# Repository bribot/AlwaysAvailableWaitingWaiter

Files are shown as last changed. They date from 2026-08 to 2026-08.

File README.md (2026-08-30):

# AlwaysAvailableWaitingWaiter

Built as an entry for a Seeed Studio contest, this is a little table-side gadget that lets restaurant guests order **by voice**, tracks what's coming and when, and shows it all on an e-paper display. Tap it onto a table with an NFC tag, press the button, say what you want, and it takes it from there.

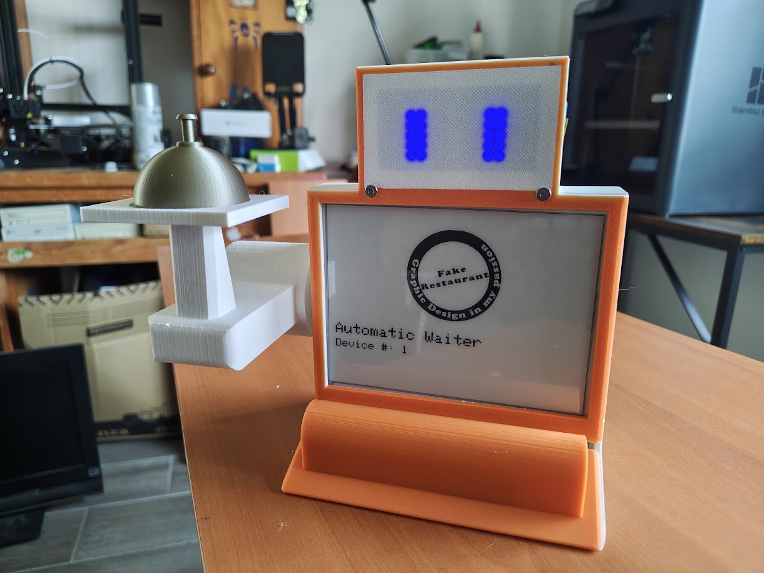
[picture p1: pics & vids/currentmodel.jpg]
Current build: orange 3D-printed waiter with LED eyes and e-paper order screen
<br>
<sub>The current model — eyes, e-paper screen, and a very serious "Fake Restaurant" test menu.</sub>

## What it actually does

- **Listens.** Press the button, say your order out loud, let go. No app, no menu-fumbling.
- **Takes orders.** You can add thing to your order just by voice.
- **Knows where it lives.** Tap an NFC tag at a table and the puck reassigns itself — same hardware, any table.
- **Has feelings, sort of.** A pair of LED matrix "eyes" blink, look around, and react while it's listening or thinking.
- **Puts it on the board.** A table-side e-paper display shows the live order — items, prices, prep time — updating as dishes go out.

<p align="center">
  <video src="pics%20&%20vids/screen_video.mp4" controls width="480">
    Your viewer doesn't do inline video — <a href="pics%20&%20vids/screen_video.mp4">watch the e-paper display in action here</a>.
  </video>
</p>

## The hardware

Two custom devices, built around these core parts:

- **5.83" Monochrome eInk / ePaper Display** — 648×480 pixels, the table-side order board
- **XIAO ePaper Display Board (ESP32-S3) — EE04** — drives the display
- **reSpeaker Lite 2-Mic Array Voice Kit** — the Waiter's ears and voice

| Device | What it's for | Lives in |
|---|---|---|
| **The Waiter** | mic + speaker, NFC reader, LED "eyes", call button | [`Audio/seeedSpeaker`](Audio/seeedSpeaker) |
| **The Board** | e-paper table display showing the live order | [`Screen`](Screen) |

Under the hood there's also an NFC reader board (PN532) for the table-tap trick:

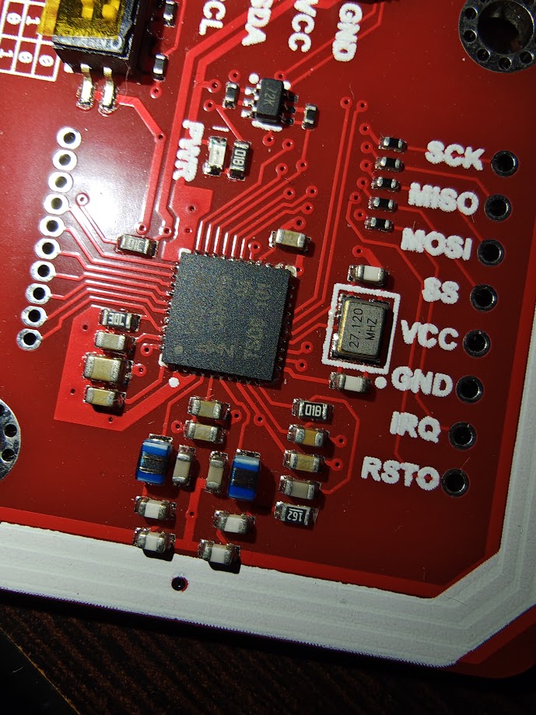
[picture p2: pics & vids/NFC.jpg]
Close-up of the PN532 NFC reader board
<br>
<sub>The part that lets the Waiter figure out which table it's sitting on.</sub>

Everything physical was designed from scratch and printed at home:

- **[`ME/`](ME)** — the enclosure: body, bell-shaped dome, arm, bottom plate (with a battery variant), all as SolidWorks parts + STL + gcode pre-sliced.
- **[`EE/button`](EE/button)** — a small custom KiCad PCB for the call button, gerbers included.

## How it works

The devices don't do the thinking themselves — they talk over Wi-Fi to a small backend that keeps track of tables, menus, and orders, and turns a voice clip into a structured order using speech recognition plus a language model on the other end (OLLAMA+whisper).

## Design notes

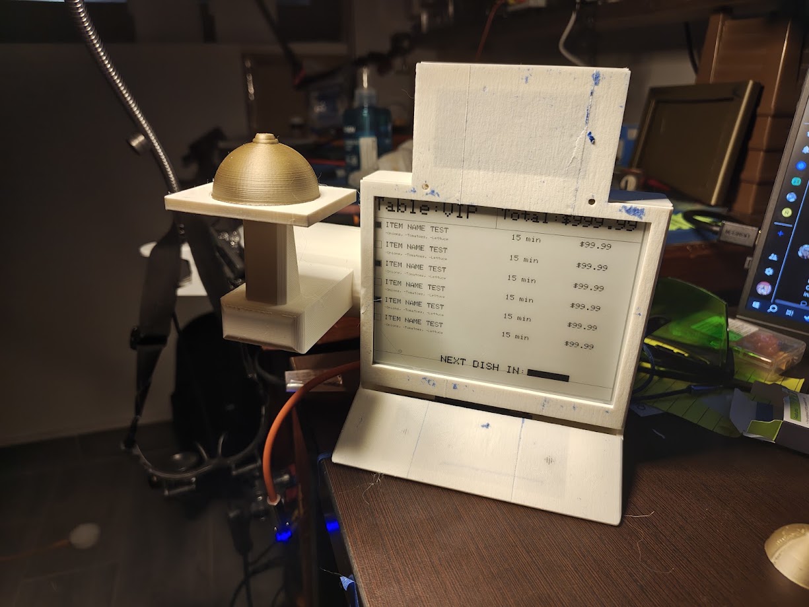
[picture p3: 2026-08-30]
pics & vids/earlyversion.jpg

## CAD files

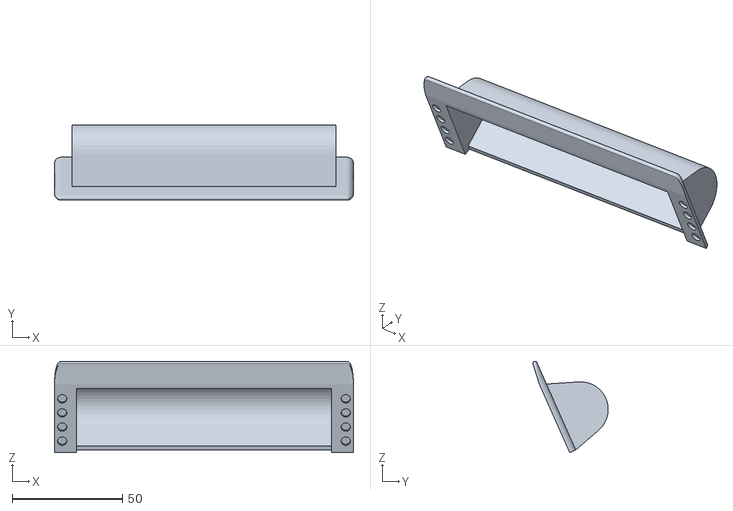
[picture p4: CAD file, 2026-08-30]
ME/bottom_plate_battery.STL
135.6 x 34.2 x 41.4

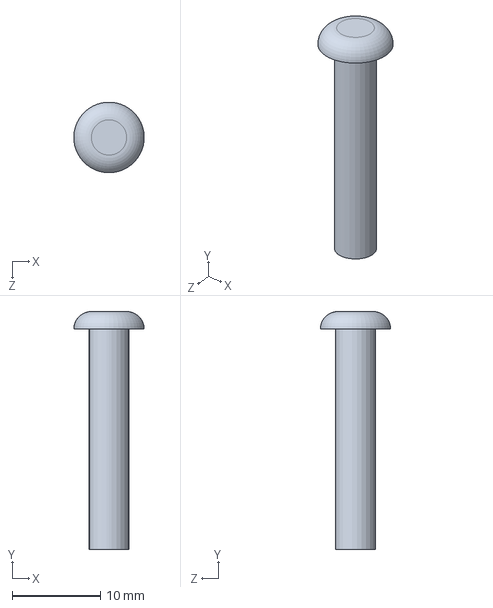
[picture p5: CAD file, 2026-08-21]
ME/bell_top.SLDPRT
8.00 x 27.0 x 7.99 mm

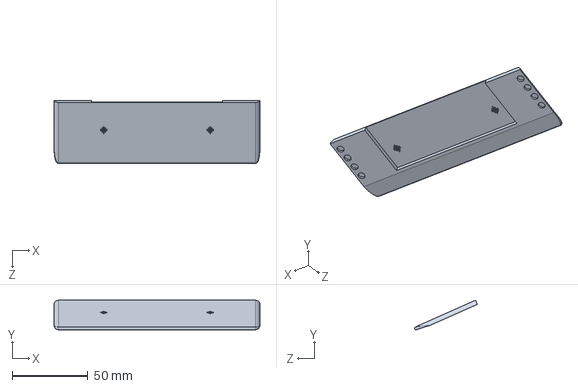
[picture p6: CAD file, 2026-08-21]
ME/bottom_plate.SLDPRT
135.6 x 19.5 x 41.4 mm

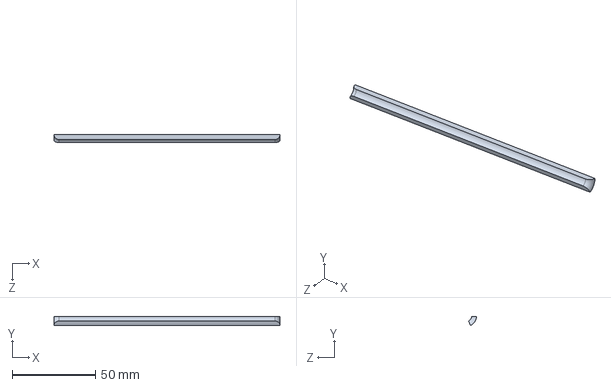
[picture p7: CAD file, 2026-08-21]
ME/middle_union.SLDPRT
135.6 x 5.48 x 4.78 mm

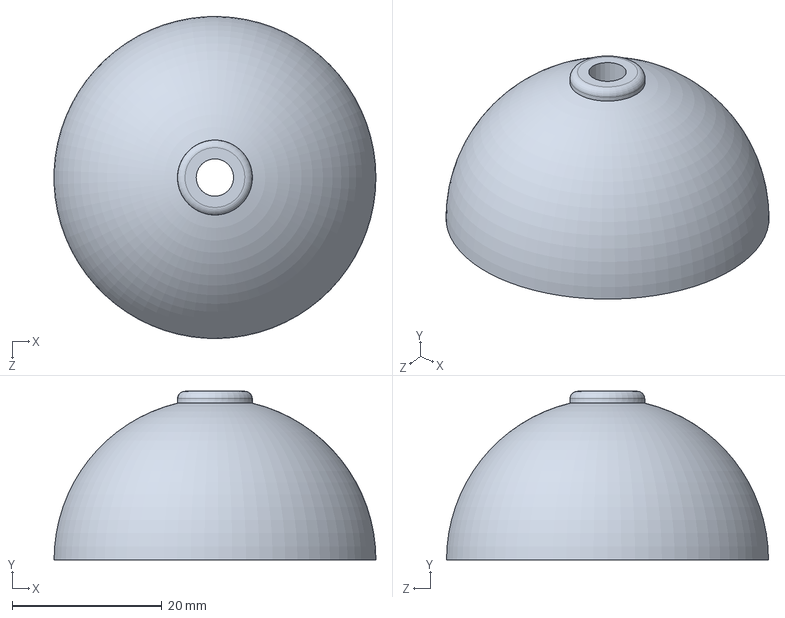
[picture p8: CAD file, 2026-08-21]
ME/bell.SLDPRT
43.0 x 22.5 x 43.0 mm

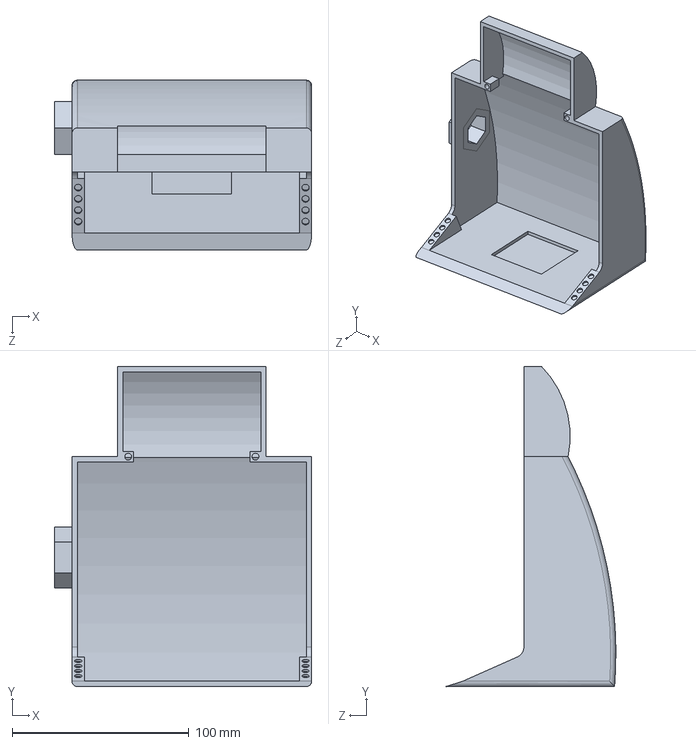
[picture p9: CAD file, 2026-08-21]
ME/body.SLDPRT
145.6 x 181.0 x 96.0 mm

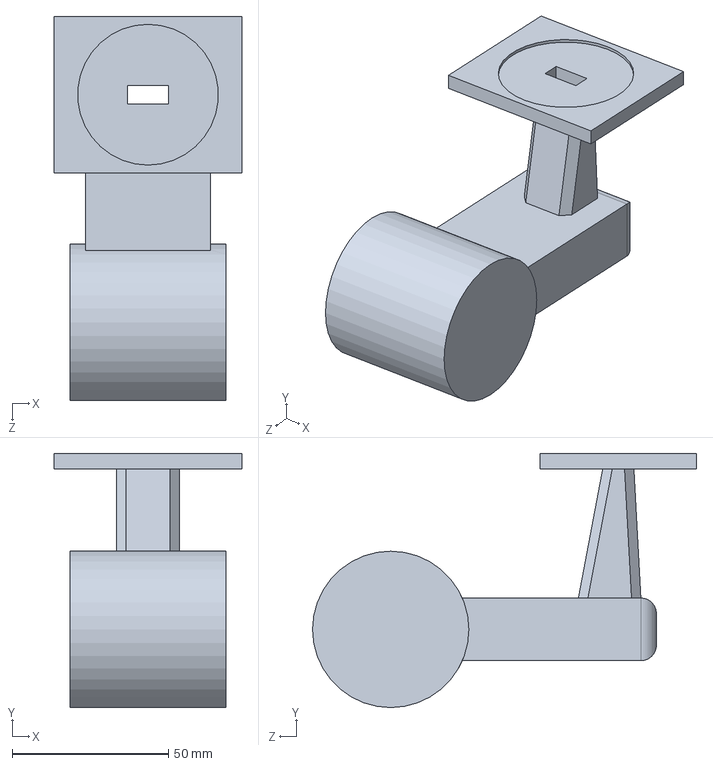
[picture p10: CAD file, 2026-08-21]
ME/arm.SLDPRT
60.0 x 81.3 x 122.8 mm

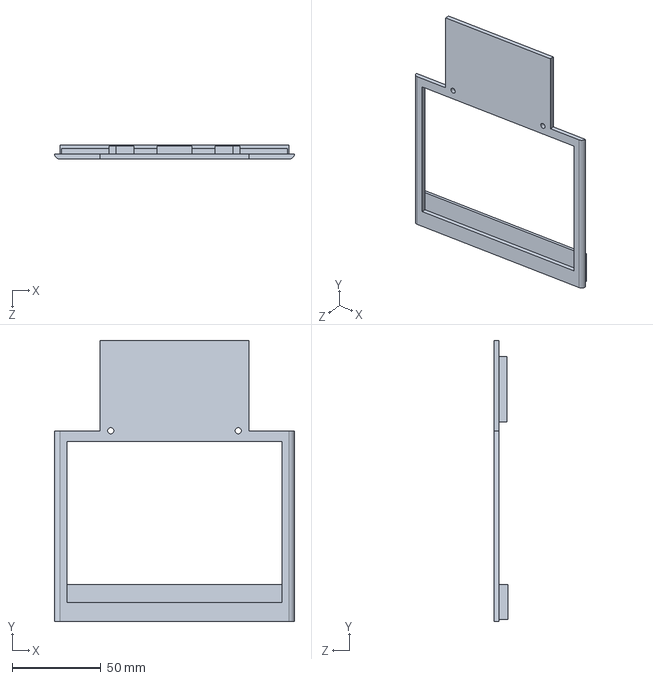
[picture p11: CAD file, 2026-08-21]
ME/front_plate.SLDPRT
135.6 x 158.8 x 8.00 mm

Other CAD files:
ME/arm.STL
ME/bell.STL
ME/bell_top.STL
ME/body.STL
ME/bottom_plate.STL
ME/front_plate.STL
ME/middle_union.STL

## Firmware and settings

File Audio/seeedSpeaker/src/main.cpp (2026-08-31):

/*
 * Voice ordering mic - XIAO ESP32S3 + ReSpeaker Lite
 *
 * Push-to-talk: hold the button on D3, speak, release. The clip goes to the
 * restaurant server over a WebSocket, which hands it to Gemini and stages the
 * parsed items into that table's pending order for confirmation.
 *
 * The table number isn't hardcoded - on boot (and on every reconnect) this
 * calls GET /device/{DEVICE_NUMBER}, the same lookup the e-paper display
 * uses, so reassigning a table's hardware doesn't require reflashing.
 *
 * Wire protocol (see Server/README.md, "Voice ordering"):
 *   -> {"type":"start"}     button pressed
 *   -> <binary frames>      raw 16-bit mono PCM @ 16 kHz, little-endian
 *   -> {"type":"stop"}      button released
 *   <- ready | listening | processing | result | error | cancelled | pong
 *
 * The ReSpeaker Lite is the I2S master and gives us 32-bit stereo frames. We
 * take the left channel and shift down to 16-bit before sending: a quarter of
 * the bytes over Wi-Fi, and exactly what the server expects.
 */
#include <Arduino.h>

#include <ArduinoJson.h>
#include <ArduinoWebsockets.h>
#include <HTTPClient.h>
#include <WiFi.h>
#include <Wire.h>
#include <Adafruit_PN532.h>
#include <Adafruit_GFX.h>
#include <Adafruit_LEDBackpack.h>

#include "AudioTools.h"
#include "board_pins.h"
#include "secrets.h"
#include "eye_emotes.h"
#include <Adafruit_NeoPixel.h>

using namespace websockets;

// ------------------------------- config -------------------------------------


#define LED_MATRIX_LEFT 0x70
#define LED_MATRIX_RIGHT 0x71

static const char *WIFI_SSID_ = WIFI_SSID;
static const char *WIFI_PASS_ = WIFI_PASSWORD;
String serverURL = SERVER_URL;
static const uint16_t PORT = PORT_NUM;
static uint8_t deviceNumber = DEVICE_NUMBER;

// Resolved from GET /device/{DEVICE_NUMBER}".
static int TABLE_NUMBER = 0;

static const int BUTTON_PIN = D3;      // push-to-talk, active LOW
static const uint32_t SAMPLE_RATE = 16000;
static const uint16_t DEBOUNCE_MS = 40;
static const uint32_t MAX_UTTERANCE_MS = 30000;  // server truncates past this
static const uint32_t RECONNECT_MS = 3000;

// I2S frames arrive 32-bit stereo; we send 16-bit mono.
static const size_t FRAMES_PER_CHUNK = 256;
static const size_t I2S_CHUNK_BYTES = FRAMES_PER_CHUNK * 2 * sizeof(int32_t);

// ------------------------------- globals ------------------------------------
static Adafruit_NeoPixel pixels(NUMPIXELS, PIN, NEO_GRB + NEO_KHZ800);
static bool pixelsStarted = false;

I2SStream i2sIn;
AudioInfo micInfo(SAMPLE_RATE, 2, 32);
WebsocketsClient ws;

static int32_t i2sBuffer[FRAMES_PER_CHUNK * 2];
static int16_t pcmBuffer[FRAMES_PER_CHUNK];

static bool wsConnected = false;
static bool capturing = false;
static bool lastButtonDown = false;
static uint32_t lastButtonChange = 0;
static uint32_t captureStartedAt = 0;
static uint32_t lastReconnectAttempt = 0;
static uint16_t nfcMisses = 0;
static const uint16_t NFC_MISS_RESET_THRESHOLD = 10;


volatile bool buttonIsrPending = false;
volatile bool buttonIsrState = false;
volatile uint32_t buttonIsrTime = 0;


static uint32_t pressIsrTime = 0;
static uint32_t pumpCallCount = 0;
static uint32_t pumpBytesSent = 0;

Adafruit_PN532 nfc(-1, -1, &Wire);
Adafruit_8x8matrix eyeLeft = Adafruit_8x8matrix();
Adafruit_8x8matrix eyeRight = Adafruit_8x8matrix();

uint8_t uid[7];
uint8_t uidLength;

const uint8_t table1_uid[] = {0x04,0xAF, 0xD3, 0xAA, 0x8B, 0x26 ,0x81};
const uint8_t table2_uid[] = {0x04, 0x33, 0xCA, 0xAA, 0x8B, 0x26, 0x81};
const uint8_t table3_uid[] = {0x04, 0x42, 0x11, 0xAB, 0x8B, 0x26, 0x81};

// ------------------------------ prototypes ----------------------------------
void connectWiFi();
bool fetchAssignedTable(int &tableNumberOut);
bool connectSocket();
void onWsMessage(WebsocketsMessage message);
void onWsEvent(WebsocketsEvent event, String data);
void startCapture();
void stopCapture();
void cancelCapture();
void pumpAudio();
void setStatus(uint8_t r, uint8_t g, uint8_t b);
void initNFC();
void initMatrix(Adafruit_8x8matrix &m, uint8_t addr);
void showEyeEmote(Adafruit_8x8matrix &m, const uint8_t *emote);
void nfcTagRecon();
void changeTableNumber(uint8_t newTableNumber);

// void scanI2CBus() {
//   Serial.println("Scanning I2C bus...");
//   uint8_t found = 0;
//   for (uint8_t addr = 1; addr < 127; addr++) {
//     Wire.beginTransmission(addr);
//     if (Wire.endTransmission() == 0) {
//       Serial.printf("  device found at 0x%02X\n", addr);
//       found++;
//     }
//   }
//   if (found == 0) {
//     Serial.println("  no I2C devices found - check wiring/power");
//   }
// }

void showEyeEmote(Adafruit_8x8matrix &m, const uint8_t *emote){
    m.clear();
    m.drawBitmap(0,0,emote,8,8,LED_ON);
    m.writeDisplay();
}

void setEyes(const uint8_t *emote){
    showEyeEmote(eyeLeft,emote);
    showEyeEmote(eyeRight,emote);
}


void blinkAnimation(){
    setEyes(idle_eye);
    delay(100);
    setEyes(closed_eye);
    delay(100);
    setEyes(idle_eye);
}

void happyAnimation(){
    for(int i=0; i<3;i++){
    setEyes(happy1);
    delay(100);
    setEyes(happy2);
    delay(100);
}
}

void sideEyeAnimation(){
    setEyes(leftidle_eye);
    delay(100);
    setEyes(rightidle_eye);
    delay(100);
    setEyes(idle_eye);
}

void changeTableAnimation(uint8_t table){
    switch (table)
    {
    case 1:
        setEyes(tag1);
        break;
    case 2:
        setEyes(tag2);
        break;
    case 3:
        setEyes(tag3);
        break;
    
    default:
        break;
    }
    delay(1000);
    happyAnimation();
    sideEyeAnimation();
}


// -------------------------------- setup -------------------------------------
void setup() {
    Serial.begin(115200);
    pinMode(BUTTON_PIN, INPUT_PULLUP);
    Wire.begin();

    // delay(3000); // delay so i can connect to the serial, remove!
    //scanI2CBus();
    initNFC();
    initMatrix(eyeLeft, LED_MATRIX_LEFT);
    initMatrix(eyeRight, LED_MATRIX_RIGHT);
    happyAnimation();
    blinkAnimation();

    setStatus(40, 0, 0);  // red until we're online
    connectWiFi();

    while (!fetchAssignedTable(TABLE_NUMBER)) {
        Serial.println("[device] lookup failed, retrying...");
        delay(2000);
    }
    Serial.printf("[device] mic %d assigned to table %d\n", DEVICE_NUMBER, TABLE_NUMBER);

    auto cfg = i2sIn.defaultConfig(RX_MODE);
    cfg.copyFrom(micInfo);
    cfg.i2s_format = I2S_STD_FORMAT;
    cfg.is_master = false;
    cfg.use_apll = false;
    cfg.pin_bck = 8;
    cfg.pin_ws = 7;
    cfg.pin_data = 43;
    cfg.pin_data_rx = 44;
    i2sIn.begin(cfg);

    ws.onMessage(onWsMessage);
    ws.onEvent(onWsEvent);
    connectSocket();
}

// -------------------------------- loop --------------------------------------
void loop() {
    if (WiFi.status() != WL_CONNECTED) {
        wsConnected = false;
        capturing = false;
        setStatus(40, 0, 0);
        connectWiFi();
        return;
    }

    if (!wsConnected) {
        capturing = false;
        if (millis() - lastReconnectAttempt > RECONNECT_MS) {
            lastReconnectAttempt = millis();
            connectSocket();
        }
        delay(10);
        return;
    }

    ws.poll();

    // ---- debounced push-to-talk ----
    bool buttonDown = digitalRead(BUTTON_PIN) == LOW;
    //Serial.printf("[mic] button %s\n", buttonDown ? "down" : "up");
    if (buttonDown != lastButtonDown && millis() - lastButtonChange > DEBOUNCE_MS) {
        lastButtonChange = millis();
        lastButtonDown = buttonDown;
        if (buttonDown) {
            setEyes(attention_eye);
            startCapture();
        } else {
            stopCapture();
        }
    }

    if (capturing) {
        //Serial.printf("Capturing...");
        pumpAudio();
        // Don't let a stuck button stream forever.
        if (millis() - captureStartedAt > MAX_UTTERANCE_MS) {
            Serial.println("[mic] max utterance reached");
            stopCapture();
        }
    } else {
        // Keep draining I2S so the DMA buffers don't overflow with stale audio.
        i2sIn.readBytes((uint8_t *)i2sBuffer, I2S_CHUNK_BYTES);

        bool tagPresent = nfc.readPassiveTargetID(PN532_MIFARE_ISO14443A, uid, &uidLength, 100);

        if (tagPresent){
            nfcMisses = 0;
            nfcTagRecon();
        } else if (++nfcMisses > NFC_MISS_RESET_THRESHOLD) {
            // weird bug
            // https://github.com/espressif/arduino-esp32/issues/11374
            nfcMisses = 0;
            
        }
        Wire.end();
        Wire.begin();
    }
}

void initNFC(){
    nfc.begin();
    uint32_t version = nfc.getFirmwareVersion();
    if (!version) {
        Serial.println("PN532 not found!!");
        while (true) {
            delay(1000);
        }
    }
    nfc.SAMConfig();
}

void initMatrix(Adafruit_8x8matrix &m, uint8_t addr){
    if (!m.begin(addr, &Wire)){
        Serial.printf("Matrix %02X not found",addr);
        return;
    } 
    m.setBrightness(8);
    m.clear();
    m.writeDisplay();
}


void nfcTagRecon(){
    // Serial.print("Tag UID:");
    // for (uint8_t i = 0; i < uidLength; i++) {
    //   Serial.printf(" %02X", uid[i]);
    // }
    // Serial.println();
    // if (uidLength == sizeof(table1_uid) && memcmp(uid, table1_uid, uidLength) == 0){
    //   showEyeEmote(eyeLeft, tag_found_bmp);
    //   showEyeEmote(eyeRight, tag_found_bmp);
    // }
    uint8_t newtable = 0;
    if (uidLength == sizeof(table1_uid)){
        
            if (uid[1] == table1_uid[1]){
                newtable = 1;
            } else if (uid[1] == table2_uid[1]){
                newtable = 2;
            } else if (uid[1] == table3_uid[1])
            {
                newtable = 3;
            }
            if(newtable != 0 && newtable != TABLE_NUMBER){
                changeTableNumber(newtable);
                changeTableAnimation(newtable);
        }
        
    }
}

void changeTableNumber(uint8_t newTableNumber) {
    Serial.printf("Table changed to %d",newTableNumber);
    HTTPClient http;
    String url = serverURL + ":" + String(PORT) + "/device/" + String(deviceNumber);
    http.begin(url);
    http.addHeader("Content-Type", "application/json");
    http.PUT("{\"table_number\":" + String(newTableNumber) + "}");
    http.end();
    TABLE_NUMBER = newTableNumber;
    connectSocket();
}

// ------------------------------ networking ----------------------------------
void connectWiFi() {
    if (WiFi.status() == WL_CONNECTED) return;

    Serial.printf("[wifi] connecting to %s", WIFI_SSID_);
    WiFi.mode(WIFI_STA);
    WiFi.begin(WIFI_SSID_, WIFI_PASS_);
    while (WiFi.status() != WL_CONNECTED) {
        delay(500);
        Serial.print(".");
    }
    Serial.printf("\n[wifi] connected, ip=%s\n", WiFi.localIP().toString().c_str());
}

bool fetchAssignedTable(int &tableNumberOut) {
    HTTPClient http;
    String url = serverURL + ":" + String(PORT) + "/device/" + String(DEVICE_NUMBER);
    http.begin(url);
    int httpCode = http.GET();

    bool ok = false;
    if (httpCode == HTTP_CODE_OK) {
        String response = http.getString();
        JsonDocument doc;
        if (!deserializeJson(doc, response)) {
            tableNumberOut = doc["table_number"].as<int>();
            ok = true;
        } else {
            Serial.println("[device] failed to parse JSON");
        }
    } else {
        Serial.printf("[device] GET failed, error: %s\n", http.errorToString(httpCode).c_str());
    }
    http.end();
    return ok;
}

bool connectSocket() {
    ws.close();
    int fetched;
    if (fetchAssignedTable(fetched)) {
        if (fetched != TABLE_NUMBER) {
            Serial.printf("[device] table changed %d -> %d\n", TABLE_NUMBER, fetched);
        }
        TABLE_NUMBER = fetched;
    } else {
        Serial.println("[device] lookup failed, using last known table");
    }
    String host = serverURL;
    host.replace("http://", "");

    char url[160];
#ifdef API_KEY_STR
    snprintf(url, sizeof(url), "ws://%s:%u/table/%d/voice?device=%s&api_key=%s", host.c_str(),
             PORT, TABLE_NUMBER, DEVICE_NAME, API_KEY_STR);
#else
    snprintf(url, sizeof(url), "ws://%s:%u/table/%d/voice?device=%u", host.c_str(), PORT,
             TABLE_NUMBER, deviceNumber);
#endif

    Serial.printf("[ws] connecting to %s\n", url);
    wsConnected = ws.connect(url);
    if (wsConnected) {
        Serial.println("[ws] connected");
        setStatus(0, 30, 0);  // green: idle and ready
    } else {
        Serial.println("[ws] connect failed");
        setStatus(40, 0, 0);
    }
    return wsConnected;
}

void onWsEvent(WebsocketsEvent event, String data) {
    if (event == WebsocketsEvent::ConnectionClosed) {
        Serial.println("[ws] closed");
        wsConnected = false;
        capturing = false;
        setStatus(40, 0, 0);
    }
}

void onWsMessage(WebsocketsMessage message) {
    JsonDocument doc;
    if (deserializeJson(doc, message.data())) {
        Serial.println("[ws] unparseable message");
        return;
    }

    const char *type = doc["type"] | "";

    if (!strcmp(type, "ready")) {
        Serial.printf("[ws] ready, table=%d voice_enabled=%d\n", (int)(doc["table"] | 0),
                      (int)(doc["enabled"] | false));
        if (!(doc["enabled"] | false)) {
            Serial.println("[ws] server has no GEMINI_API_KEY - orders will fail");
            setStatus(40, 20, 0);  // amber: connected but voice is disabled
        }

    } else if (!strcmp(type, "listening")) {
        setStatus(0, 0, 60);  // blue: recording

    } else if (!strcmp(type, "processing")) {
        setStatus(30, 20, 0);  // amber: waiting on Gemini
        setEyes(wait_eye);
        Serial.printf("[ws] processing %.2fs of audio\n", (float)(doc["seconds"] | 0.0));

    } else if (!strcmp(type, "result")) {
        Serial.printf("[ws] heard: %s\n", doc["transcript"] | "");
        if (doc["confirmed"] | false) {
            Serial.println("      confirmed - pending order sent to the kitchen");
        } else if (doc["cancelled"] | false) {
            Serial.println("      cancelled - pending order cleared");
        } else {
            for (JsonObject item : doc["items"].as<JsonArray>()) {
                Serial.printf("      %dx %s%s\n", (int)(item["quantity"] | 1),
                              item["name"] | "?",
                              (item["matched"] | false) ? "" : "  <-- NOT ON MENU");
            }
            Serial.printf("[ws] %d matched, %d unmatched, staged to pending\n",
                          (int)(doc["matched_count"] | 0), (int)(doc["unmatched_count"] | 0));
        }
        setStatus(0, 30, 0);
        happyAnimation();
        setEyes(idle_eye);

    } else if (!strcmp(type, "error")) {
        Serial.printf("[ws] error: %s\n", doc["message"] | "");
        setStatus(60, 0, 0);
        delay(400);
        setStatus(0, 30, 0);
        setEyes(error);
        delay(1000);
        sideEyeAnimation();

    } else if (!strcmp(type, "cancelled")) {
        setStatus(0, 30, 0);
        setEyes(sad_eye);
        delay(1000);
        sideEyeAnimation();
    }
}

// -------------------------------- capture -----------------------------------

void startCapture() {
    if (!wsConnected) return;
    Serial.println("[mic] start");

    // Drop whatever the DMA buffered while we were idle, so the clip starts at
    // the button press instead of a second earlier.
    for (int i = 0; i < 4; i++) {
        i2sIn.readBytes((uint8_t *)i2sBuffer, I2S_CHUNK_BYTES);
    }

    capturing = true;
    captureStartedAt = millis();
    pumpCallCount = 0;
    pumpBytesSent = 0;
    ws.send("{\"type\":\"start\"}");
}

void stopCapture() {
    if (!capturing) return;
    capturing = false;
    Serial.println("[mic] stop");
    ws.send("{\"type\":\"stop\"}");
    setEyes(wait_eye);
}

void cancelCapture() {
    if (!capturing) return;
    capturing = false;
    ws.send("{\"type\":\"cancel\"}");
}

void pumpAudio() {
    pumpCallCount++;
    size_t bytesRead = i2sIn.readBytes((uint8_t *)i2sBuffer, I2S_CHUNK_BYTES);
    if (bytesRead < sizeof(int32_t) * 2) return;

    // 32-bit stereo -> 16-bit mono. Left channel only: on the ReSpeaker Lite the
    // processed mic signal is there, and averaging both channels just halves it.
    size_t frames = bytesRead / (sizeof(int32_t) * 2);
    for (size_t i = 0; i < frames; i++) {
        pcmBuffer[i] = (int16_t)(i2sBuffer[i * 2] >> 16);
    }

    if (!ws.sendBinary((const char *)pcmBuffer, frames * sizeof(int16_t))) {
        Serial.println("[ws] send failed, dropping utterance");
        capturing = false;
        wsConnected = false;
        return;
    }
    pumpBytesSent += frames * sizeof(int16_t);
}

// -------------------------------- status LED --------------------------------

void setStatus(uint8_t r, uint8_t g, uint8_t b) {
    if (!pixelsStarted) {
        pixels.begin();
        pixelsStarted = true;
    }
    pixels.setPixelColor(0, pixels.Color(r, g, b));
    pixels.show();
}

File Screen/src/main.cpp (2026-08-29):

#include <Arduino.h>
#include "TFT_eSPI.h"
#include "layout.h"
#include "secrets.h"
#include "ArduinoJson.h"
#include "HTTPClient.h"
#include "restaurant.h"

#ifdef EPAPER_ENABLE // Only compile this code if the EPAPER_ENABLE is defined in User_Setup.h
EPaper epaper;
#endif

JsonDocument doc;

// ------------Config ------------
#define deviceNumber 1

#define SleepMode 0
#define NormalMode 1
#define WaiterMode 2

#define NormalModeDelay 3000
#define WaiterModeDelay 1000
#define SleepModeDelay 10000


const char* ssid     = WIFI_SSID;
const char* password = WIFI_PASSWORD;

String serverURL = SERVER_URL;
char maxRows = 8;
// -------------------------------
// -----------globals -----------

uint8_t row = 0;
uint8_t defaultFontSize = 3;
uint8_t timePassed = 9;
char mode = NormalMode;
String jsonResponse;
String lasjsonResponse;


static char* TableString = "Table:";
//uint8_t TableNumber = 4;
static char* TotalString = "Total:";
String TotalAmount = "$0.00";
// char* TimeString = "NEXT DISH IN:";

RTC_DATA_ATTR bool mainDrawn = false;
RTC_DATA_ATTR uint8_t TableNumber = 0;
RTC_DATA_ATTR uint8_t OrderID = 0;
RTC_DATA_ATTR bool splashDrawn = false;
bool itemsDrawn = false; 

void drawPartialString(const char* text, Rect_t rect, uint8_t fontsize = defaultFontSize);
void drawItem(int row, const char* name, const char* price, const char* detail, const float time, bool checked = false);
void drawCheckBox(Rect_t rect, bool checked);
void startupScreen();
void drawTotal(const char* totalAmount);
void drawProgressBar(float progress);
bool fetchOrders(String &jsonResponse, uint8_t tableNumber);
void normalMode();
void waiterMode();
void sleepMode();
void fetchCurrentTable();
void changeTableNumber(uint8_t newTableNumber);
void drawWaiterModeScreen();
bool fetchPendingOrders(String &jsonResponse, uint8_t tableNumber);
bool checkPending();
void goToSleep(uint32_t ms);
void drawSplashScreen();



// char* ItemName = "ITEM NAME TEST";
// char* ItemPrice = "$99.99";
// char* ItemDetail = "-Onions, -Tomatoes, -Lettuce";
// char* ItemTime = "15 min";
// bool ItemDelivered = false;

float NexDishProgress = 0.5;

void setup()
{
    //delay(3000);
    Serial.begin(115200);
    Serial.println("Starting up...");

    // Connect to Wi-Fi
    WiFi.begin(ssid, password);
    Serial.print("Connecting to Wi-Fi");
    while (WiFi.status() != WL_CONNECTED) {
        delay(500);
        Serial.print(".");
    }
    Serial.println();
    Serial.println("Connected to Wi-Fi");
    Serial.print("IP Address: ");
    Serial.println(WiFi.localIP());

    fetchCurrentTable();
    //Serial.printf("Current table number: %s\n", TableNumber.c_str());
    epaper.begin();
    epaper.fillScreen(TFT_WHITE);
    // Rect_t testRect = getItemRect(0);
    //Rect_t testRect_t = getItemTimeRect(testRect);
    
    

    if (OrderID == 0) {
        Serial.println("No order ID found, going to sleep");
        sleepMode();
    }
    if (!mainDrawn) {
        epaper.update();
        startupScreen();
        epaper.update(); // update the display
        mainDrawn = true;
    }

    if (checkPending()) {
        mode = WaiterMode;
    } else {
        mode = NormalMode;
    }

    if (mode == WaiterMode) {
        itemsDrawn = false;
        while (checkPending()) {
            waiterMode();
        }
        mainDrawn = false;
    } else if (mode == NormalMode) {
        normalMode();
    } 

    goToSleep(NormalModeDelay);
}

void goToSleep(uint32_t ms) {
    esp_sleep_enable_timer_wakeup((uint64_t)ms * 1000ULL);
    esp_deep_sleep_start();
}

void drawdebugmark(){
    epaper.fillCircle(10, 10, 50, TFT_BLACK);
    epaper.updataPartial(5, 5, 10, 10);
    delay(1000);
    epaper.fillCircle(10, 10, 50, TFT_WHITE);
    epaper.updataPartial(5, 5, 10, 10);
}

void loop()
{
    // it's too quiet in here
}

void waiterMode() {
    drawWaiterModeScreen();
    delay(WaiterModeDelay);
}
void sleepMode() {
    if (!splashDrawn) {
        drawSplashScreen();
    }
    splashDrawn = true;
    mainDrawn = false;
    goToSleep(SleepModeDelay);
}
void normalMode() {
    if (fetchOrders(jsonResponse, TableNumber)) {
        DeserializationError error = deserializeJson(doc, jsonResponse);
        if (!error) {
            JsonArray items = doc.as<JsonArray>();
            float temp_total = 0.0;
            for (JsonObject item : items) {
                const char* itemName = item["itemName"];
                const char* itemDetails = item["details"];
                const float itemPrice = item["price"];
                const float itemTime = item["time"];
                bool itemDelivered = item["delivered"];

                temp_total += itemPrice;

                if (row < maxRows) {
                    drawItem(row, (char*)itemName, String(itemPrice, 2).c_str(), (char*)itemDetails, itemTime, itemDelivered);
                }
                row = (row + 1);
            }
            row = 0;
            TotalAmount = "$" + String(temp_total, 2);
            drawTotal(TotalAmount.c_str());
    }}
}

void drawSplashScreen() {
    epaper.fillScreen(TFT_WHITE);
    epaper.drawRect(0, 0, EPD_WIDTH, EPD_HEIGHT, TFT_BLACK);

    int16_t logoX = (EPD_WIDTH - RESTAURANT_LOGO_WIDTH) / 2;
    int16_t logoY = 50;
    epaper.drawXBitmap(logoX, logoY, restaurant_logo_bits, RESTAURANT_LOGO_WIDTH, RESTAURANT_LOGO_HEIGHT, TFT_BLACK);

    epaper.setTextColor(TFT_BLACK);
    epaper.setTextSize(4);
    epaper.setCursor(20, logoY + RESTAURANT_LOGO_HEIGHT + 30);
    epaper.print("Automatic Waiter");
    epaper.setTextSize(3);
    epaper.setCursor(20, logoY + RESTAURANT_LOGO_HEIGHT + 75);
    epaper.print("Device #: ");
    epaper.print(deviceNumber);
    epaper.update();
}
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

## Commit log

2026-08-21 init screen code, ME and EE done
    [Seeed_buttonmodule.kicad_pcb, Seeed_buttonmodule.kicad_sch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]
2026-08-30 there's a bug in the NFC module com
    [bottom_plate_battery.STL]
2026-08-30 some cad files deleted
    [robowaiterV1.SLDASM]
2026-08-30 README added
    [bottom_plate_battery.SLDPRT, menu.csv]
2026-08-30 Revert "README added"
    This reverts commit 671d5c7fc2cbd3bed802a15d46e9c0c20acbe4a3.
    [bottom_plate_battery.SLDPRT, menu.csv]
2026-08-31 NFC bug workaround, no more interrupts in the button, some cleaning
    [main.cpp]
